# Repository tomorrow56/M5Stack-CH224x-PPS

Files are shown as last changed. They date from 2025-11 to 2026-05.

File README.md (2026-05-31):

# M5Stack-CH224x-PPS

An Arduino library and sample sketch collection for controlling CH224A/CH224Q USB PD controllers via I2C on M5Stack (M5Unified compatible), with USB PD PPS/AVS mode voltage adjustment.

## Features

- **Fixed Voltage Mode**: Select from 5V/9V/12V/15V/20V/28V fixed voltages
- **PPS Mode**: Adjust voltage in 0.1V steps within 5.0V～21.0V range
- **AVS Mode**: Variable voltage setting (16-bit precision)
- **Source Capabilities Analysis**: Detailed display of SRCCAP/EPR_SRCCAP messages
- **PDO Type Identification**: Automatic detection of Fixed/Battery/Variable/PPS Supply
- **CH224A Library**: Reusable library class (`src/CH224A.h`)

## Project Structure

```text
M5Stack-CH224x-PPS/
├── src/
│   ├── CH224A.h          # CH224A library header
│   └── CH224A.cpp        # CH224A library implementation
├── examples/
│   ├── M5Stack_PDtrigger_PPS/             # PD Analyzer with PDO decode
│   └── test/                              # Test and debug sketches
│       ├── M5Stack_CH224A_PPS/            # PPS voltage control (with GUI)
│       ├── CH224A_PDO_Test/               # PDO decode test (serial output)
│       ├── I2C_Scanner/                   # I2C device scanner
│       ├── PPS_Test/                      # PPS voltage sweep test
│       └── Simple_Test/                   # Fixed voltage auto-switch test
├── kicad/                                 # KiCad design files
│   └── M5_PDtrigger_PPS_v2/               # Hardware design v2
├── case/                                  # 3D printable case files
│   └── M5Stack_PDtrigger/                 # M5Stack PD Trigger case
├── README_JP.md           # Japanese documentation
├── README.md             # This file
├── WIRING.md             # Detailed wiring information
└── LICENSE               # MIT license
```

## Hardware Requirements

### Required Components

- **M5Stack** (M5Unified compatible device: Core Basic, Core2, CoreS3, etc.)
- **CH224A/CH224Q** USB PD controller (ESSOP10/DFN10 package)
- **USB Type-C connector**
- **1μF ceramic capacitor** (between VHV-GND)

### Pin Connections

| M5Stack | CH224A | Description |
|---|---|---|
| GPIO21 | Pin 3 (CFG3/SDA)| I2C data line |
| GPIO22 | Pin 2 (CFG2/SCL)| I2C clock line |
| GND | Pin 0 (GND) | Ground |
| GPIO2 (※) | VBUSEN | Output enable |
| GPIO12 (※) | Pin 10 (PG) | Power Good input |

※ Used in sample sketches. Can be changed according to your purpose.

**Important**: When using CFG2/CFG3 pins as I2C, do not connect resistors to these pins (leave them floating).

For detailed wiring information, see [WIRING.md](WIRING.md).

## 3D Printable Case

A custom 3D printable case is available for the M5Stack PD Trigger:

### Files Available

- **`case/M5Stack_PDtrigger/PDtrigger_10mm_224A.stl`** - Main case body (STL format)
- **`case/M5Stack_PDtrigger/PDtrigger_10mm_224A.3mf`** - Main case body (3MF format)
- **`case/M5Stack_PDtrigger/text.stl`** - Text labels/decorations (STL format)

### Printing Recommendations

- **Layer Height**: 0.2mm for quality
- **Infill**: 20-30% 
- **Support**: Required for overhangs
- **Material**: PLA or PETG recommended

The case is designed to accommodate the CH224A/CH224Q PD controller and provide proper mounting for the M5Stack device.

## Software Requirements

### Arduino IDE Setup

1. **Add M5Stack Board Manager**:
   - Arduino IDE → File → Preferences
   - Add to "Additional Board Manager URLs":

     ```text
     https://m5stack.oss-cn-shenzhen.aliyuncs.com/resource/arduino/package_m5stack_index.json
     ```

2. **Install M5Stack Board**:
   - Tools → Board → Boards Manager
   - Search for "M5Stack" and install

3. **Install M5Unified Library**:
   - Sketch → Include Library → Manage Libraries
   - Search for "M5Unified" and install

### Board Settings

- **Board**: M5Stack-Core-ESP32 (or your M5Stack device)
- **Upload Speed**: 921600
- **Flash Frequency**: 80MHz

## Sample Sketches

### M5Stack_PDtrigger_PPS

M5Stack PD Analyzer - Main application for USB PD charger analysis and voltage control.

**Key Features**:

- Fixed voltage mode switching (5V/9V/12V/15V/20V)
- PPS mode voltage adjustment (0.1V steps)
- PDO Decode screen for detailed Source Capabilities display
- Real-time voltage/current measurement and PG (Power Good) display

**Operation**:

- **Button A (Left)**: Decrease voltage / Enter PDO Decode at PDO=0
- **Button B (Center)**: Output ON/OFF toggle
- **Button C (Right)**: Increase voltage / Enter PPS control at PDO=4 / Exit from PDO Decode

### M5Stack_CH224A_PPS

Legacy version of PPS voltage control GUI application.

### test/ Folder

Contains the following test and debug sketches.

#### CH224A_PDO_Test

Debug sketch that outputs PDO data to serial monitor. Displays raw data and parsed results of Source Capabilities.

#### I2C_Scanner

Scans I2C bus and displays device addresses. Used for CH224A connection verification.

#### PPS_Test

Test sketch that automatically sweeps PPS voltage from 5.5V to 20.0V in 0.5V steps.

#### Simple_Test

Basic test sketch that automatically switches fixed voltages (5V→9V→12V→15V→20V→28V) every 2 seconds.

## CH224A Library

Provides a reusable library class in `src/CH224A.h` and `src/CH224A.cpp`.

### Usage Example

```cpp
#include <Wire.h>
#include "src/CH224A.h"

CH224A ch224a;

void setup() {
  Wire.begin(21, 22);
  
  if (ch224a.begin()) {
    // Fixed voltage setting
    ch224a.setVoltage9V();
    
    // PPS voltage setting (9.5V)
    ch224a.setPPSVoltage(9.5);
    
    // AVS voltage setting (12.0V)
    ch224a.setAVSVoltage(12.0);
  }
}
```

### API

| Method | Description |
|---|---|
| `begin(TwoWire &wire)` | Initialize and check connection |
| `isConnected()` | Check I2C connection |
| `setVoltage5V()` ～ `setVoltage28V()` | Fixed voltage setting |
| `setFixedVoltage(CH224A_VoltageMode)` | Voltage mode setting |
| `setPPSVoltage(float voltage)` | PPS voltage setting (in volts) |
| `setPPSVoltageRaw(uint8_t value)` | PPS voltage setting (0.1V units) |
| `setAVSVoltage(float voltage)` | AVS voltage setting (in volts) |
| `setAVSVoltageRaw(uint16_t value)`| AVS voltage setting (0.1V units) |
| `readRegister(reg, &value)` | Register read |
| `writeRegister(reg, value)` | Register write |
| `readSourceCapabilities(data, length)` | Read Source Capabilities |
| `getPDOCount(header)` | Get PDO count |
| `getPDOType(pdo)` | Get PDO type (0:Fixed, 1:Variable, 3:PPS) |
| `parseFixedPDO(pdo, voltage, current)` | Parse Fixed PDO |
| `parseVariablePDO(pdo, minV, maxV, current)` | Parse Variable PDO |
| `parsePPSPDO(pdo, minV, maxV, current)` | Parse PPS PDO |
| `decodeHeader(header)` | Decode and display PDO header |
| `decodePDOs(data, numPDO)` | Decode and display PDO data |

## CH224A Technical Specifications

### Supported Protocols

- USB PD3.2 EPR (Extended Power Range)
- USB PD PPS (Programmable Power Supply)
- USB PD AVS (Adjustable Voltage Supply)
- USB PD SPR (Standard Power Range)
- BC1.2

### Electrical Specifications

- **Input Voltage Range**: 4V～30V
- **I2C Communication Speed**: Max 400kHz
- **I2C Address**: 0x22 (default) or 0x23

### Register Map

| Address | Name | Description |
|---|---|---|
| 0x09 | I2C_STATUS | I2C status |
| 0x0A | VOLTAGE_CTRL | Voltage control (0-7) |
| 0x50 | CURRENT_DATA | Current data (50mA units) |
| 0x51-0x52  | AVS_VOLTAGE | AVS voltage (16-bit) |
| 0x53 | PPS_VOLTAGE | PPS voltage (0.1V units) |
| 0x60-0x7F  | SRCCAP_DATA | Source Capabilities |
| 0x80-0x8F  | EPR_SRCCAP_DATA | EPR Source Capabilities |

### Voltage Control Register (0x0A) Values

| Value | Mode |
|---|---|
| 0 | 5V Fixed |
| 1 | 9V Fixed |
| 2 | 12V Fixed  |
| 3 | 15V Fixed  |
| 4 | 20V Fixed  |
| 5 | 28V Fixed  |
| 6 | PPS Mode |
| 7 | AVS Mode |

## Troubleshooting

### CH224A Not Responding

1. Check SDA/SCL wiring
2. Verify I2C address (use `I2C_Scanner` sketch)
3. Ensure no resistors are connected to CFG2/CFG3 pins
4. Add 4.7kΩ pull-up resistors if necessary

### Voltage Not Changing

1. Verify that the USB PD charger supports PPS/AVS
2. Use a USB PD compatible cable
3. Ensure settings are within the charger's supported voltage range

### Screen Not Displaying

1. Verify M5Unified library is properly installed
2. Check that the correct board is selected

## License

MIT License - see [LICENSE](LICENSE) for details

## References

- [CH224A Datasheet](https://wch.cn)
- [M5Stack Official Documentation](https://docs.m5stack.com)
- [M5Unified GitHub](https://github.com/m5stack/M5Unified)
- [USB Power Delivery Specification](https://www.usb.org/usb-charger-pd)

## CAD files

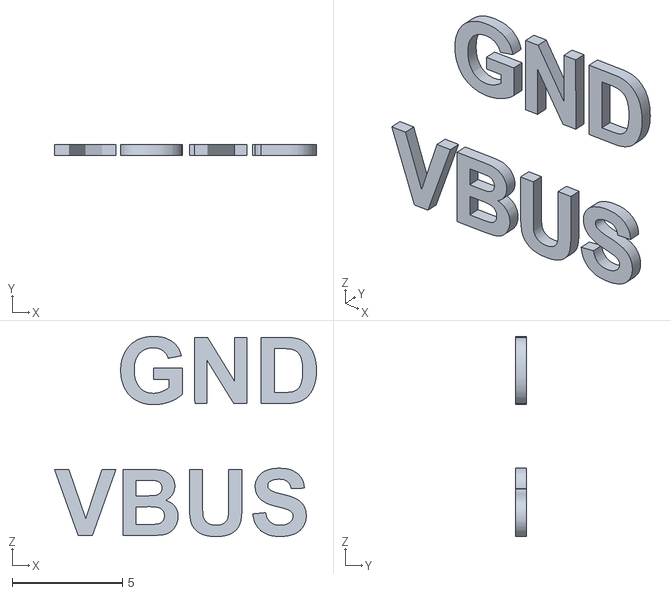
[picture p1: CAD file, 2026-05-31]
case/M5Stack_PDtrigger/text.stl
11.9 x 0.5 x 9.09

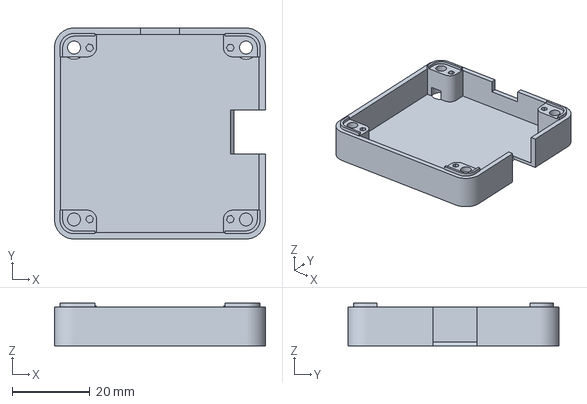
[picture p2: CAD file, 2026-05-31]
case/M5Stack_PDtrigger/PDtrigger_10mm_224A.3mf
54.3 x 54.3 x 11.1 mm
PDtrigger_10mm_224A.stl
text.stl

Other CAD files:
case/M5Stack_PDtrigger/PDtrigger_10mm_224A.stl

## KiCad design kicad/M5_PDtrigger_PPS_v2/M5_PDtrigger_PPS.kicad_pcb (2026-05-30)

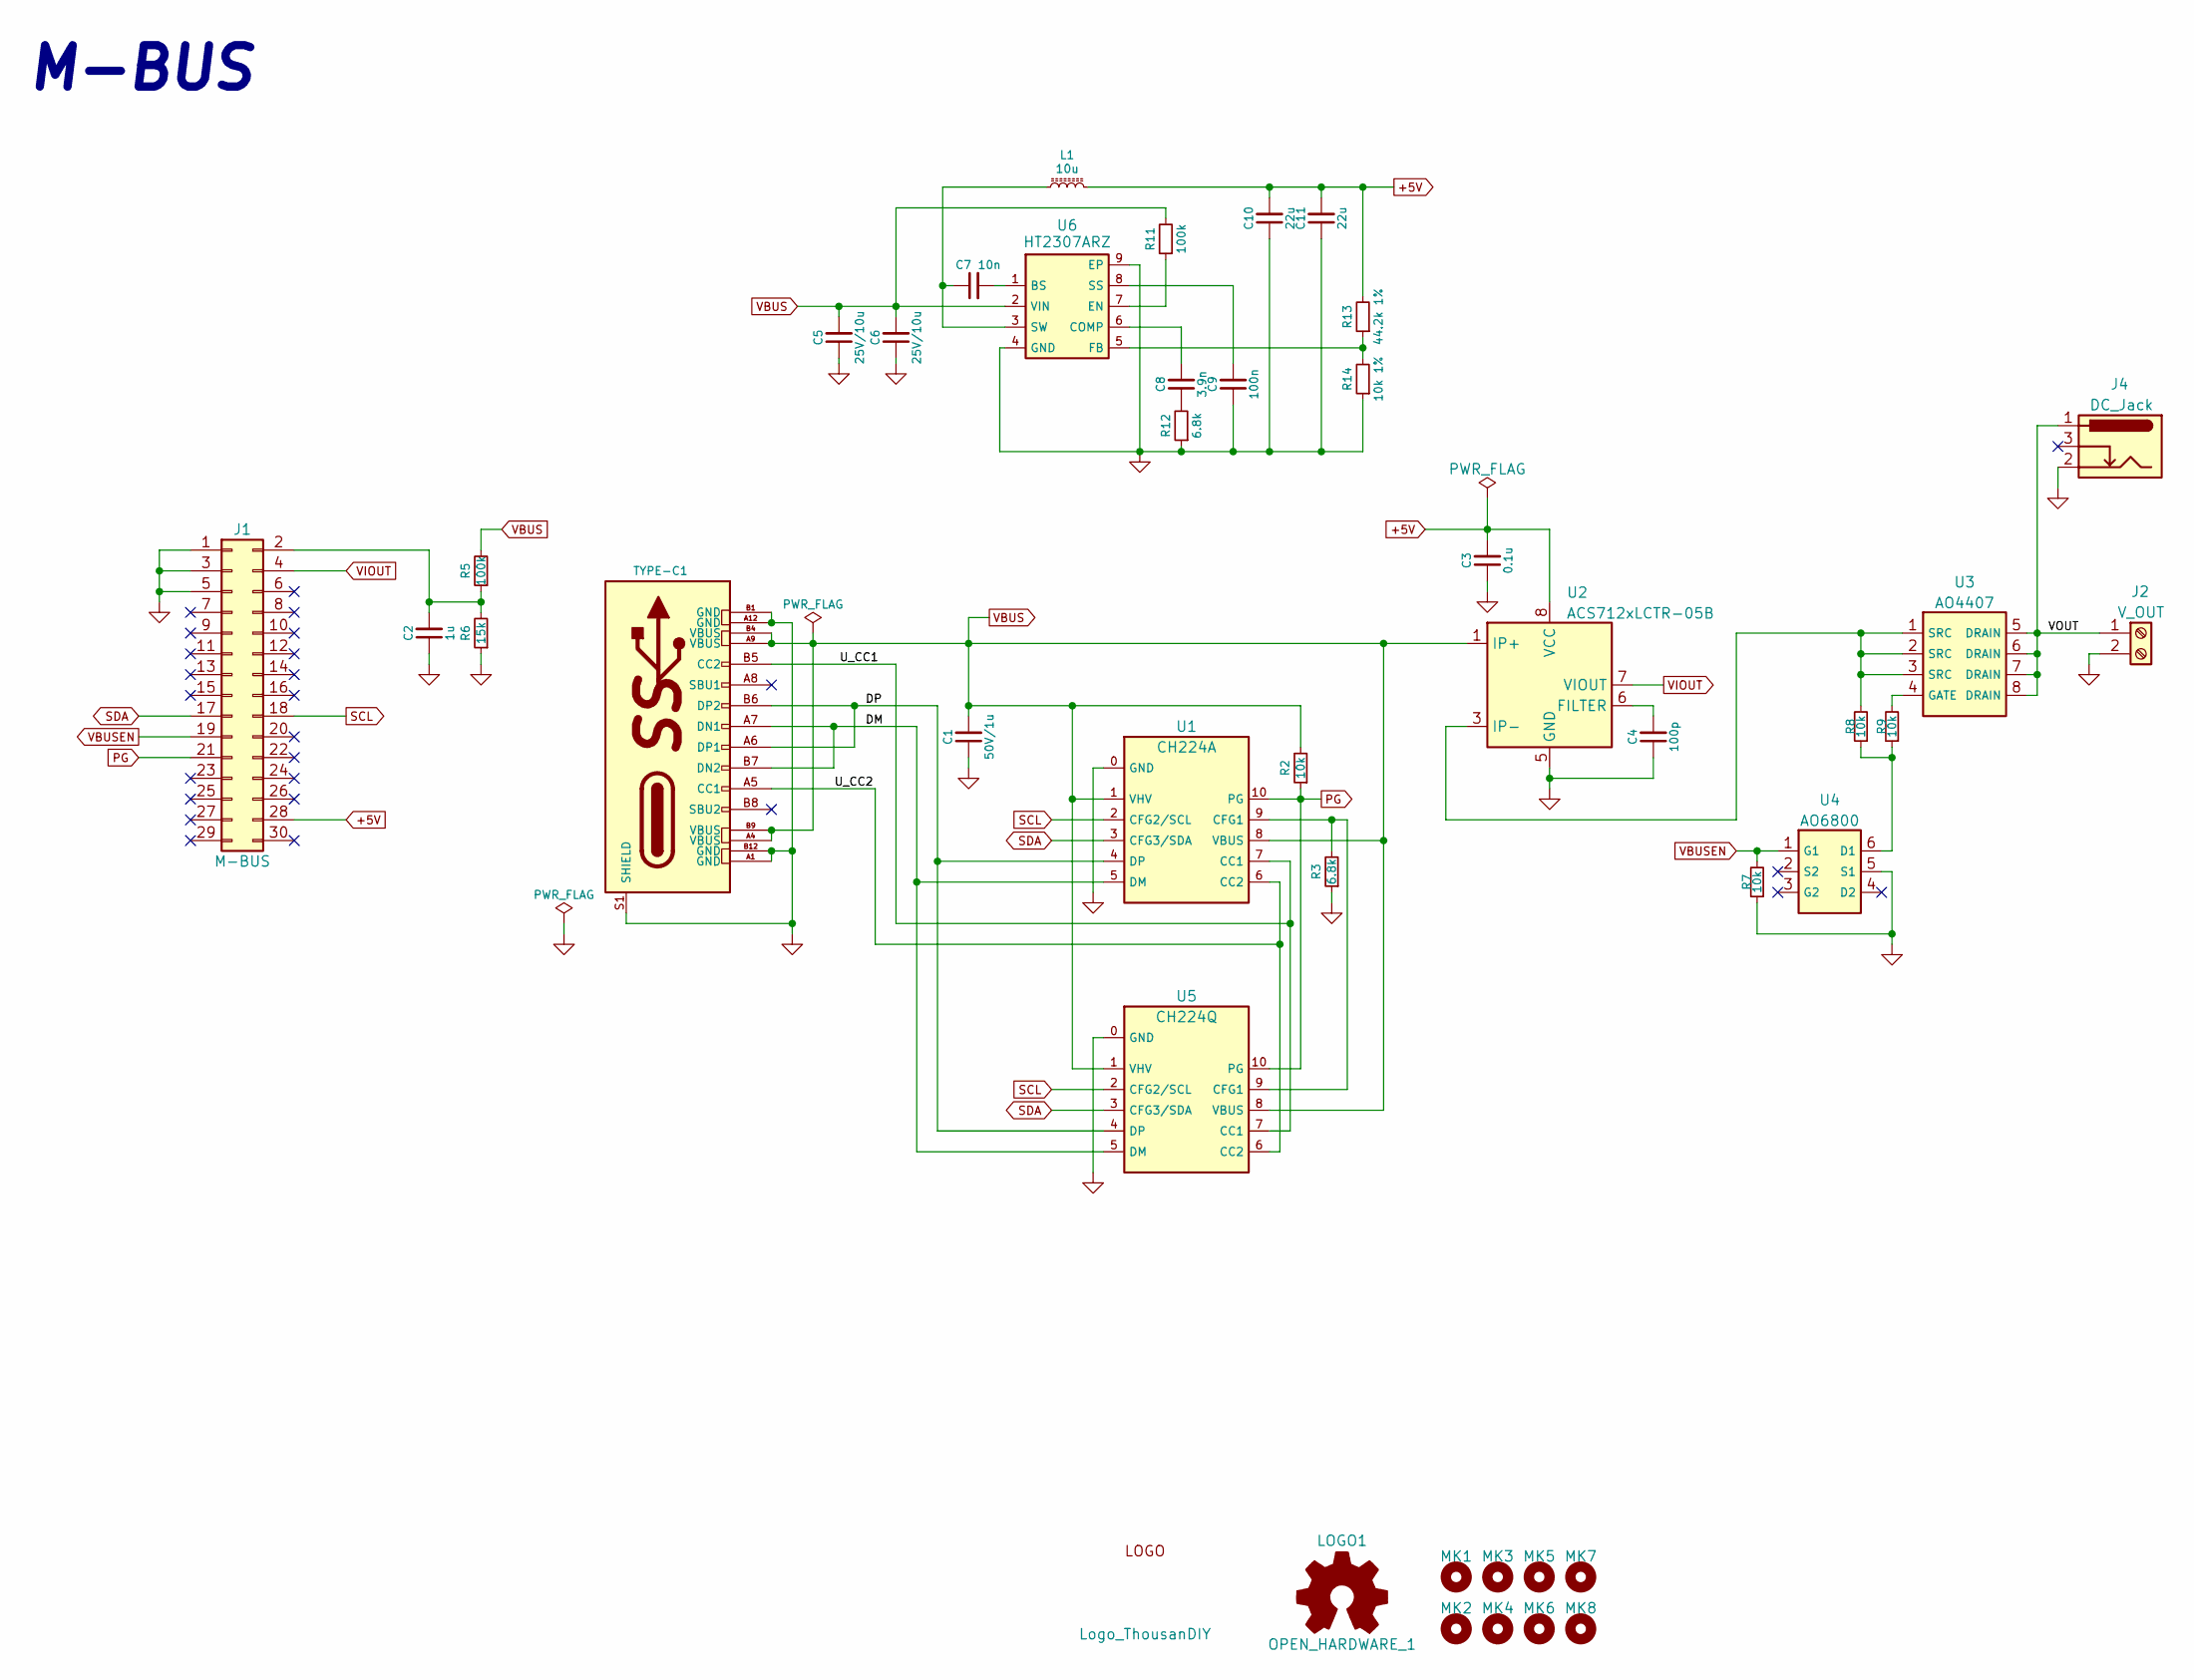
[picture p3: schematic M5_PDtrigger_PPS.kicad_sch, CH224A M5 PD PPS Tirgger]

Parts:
C1: 50V/1u; C_0603_1608Metric
C2: 1u; C_0603_1608Metric
C3: 0.1u; C_0603_1608Metric
C4: 100p; C_0603_1608Metric
C5, C6: 25V/10u; C_0603_1608Metric
C7: 10n; C_0603_1608Metric
C8: 3.9n; C_0603_1608Metric
C9: 100n; C_0603_1608Metric
C10, C11: 22u; C_0603_1608Metric
J1: M-BUS; Pin_Header_MBUS_SMD_TH
J2: V_OUT; TB111-2-2
J4: DC_Jack; BarrelJack_Horizontal
L1: 10u; L_Chilisin_BMRB00050518-B
LOGO1: OPEN_HARDWARE_1; OSHW-logo_silkscreen-front_3mm
MK1, MK2, MK3, MK4: Mounting_Hole; MountingHole_M3_mod
MK5, MK6, MK7, MK8: Mounting_Hole; MountingHole_M2_mod
R2, R7, R8, R9: 10k; R_0603_1608Metric
R3, R12: 6.8k; R_0603_1608Metric
R5, R11: 100k; R_0603_1608Metric
R6: 15k; R_0603_1608Metric
R13: 44.2k 1%; R_0603_1608Metric
R14: 10k 1%; R_0603_1608Metric
TYPE-C1: TYPE-C-31-M-12; USB_C_Receptacle_HRO_TYPE-C-31-M-12
U1: CH224A; ESSOP-10_3.9x4.9mm_P1.00mm_ThermalVia
U2: ACS712xLCTR-05B; SOIC-8_3.9x4.9mm_P1.27mm
U3: AO4407; SOP-8_3.9x4.9mm_P1.27mm
U4: AO6800; SOT-23-6
U5: CH224Q; DFN-10_2x2mm_P0.4mm_ThermalVia
U6: HT2307ARZ; HSOP-8-1EP_3.9x4.9mm_P1.27mm_EP2.41x3.1mm_ThermalVias
logo2: Logo_ThousanDIY; TDIY-LOGO-S

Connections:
+5V: C3.2, C10.2, C11.2, J1.28, L1.2, R13.2, U2.8 (VCC)
/DM: TYPE-C1.A7 (DN1), TYPE-C1.B7 (DN2), U1.5 (DM), U5.5 (DM)
/DP: TYPE-C1.A6 (DP1), TYPE-C1.B6 (DP2), U1.4 (DP), U5.4 (DP)
/U_CC1: TYPE-C1.B5 (CC2), U1.7 (CC1), U5.7 (CC1)
/U_CC2: TYPE-C1.A5 (CC1), U1.6 (CC2), U5.6 (CC2)
/VOUT: J2.1, J4.1, U3.5 (DRAIN), U3.6 (DRAIN), U3.7 (DRAIN), U3.8 (DRAIN)
GND: C1.1, C2.1, C3.1, C4.1, C5.1, C6.1, C9.1, C10.1, C11.1, J1.1, J1.3, J1.5, J2.2, J4.2, R3.1, R6.1, R7.1, R12.1, R14.1, TYPE-C1.A1 (GND), TYPE-C1.A12 (GND), TYPE-C1.B1 (GND), TYPE-C1.B12 (GND), TYPE-C1.S1 (SHIELD), U1.0 (GND), U2.5 (GND), U4.5 (S1), U5.0 (GND), U6.4 (GND), U6.9 (EP)
unnamed: C8.1, R12.2
unnamed: C2.2, J1.2, R5.1, R6.2
unnamed: R8.2, U2.3 (IP-), U2.4 (IP-), U3.1 (SRC), U3.2 (SRC), U3.3 (SRC)
unnamed: R3.2, U1.9 (CFG1), U5.9 (CFG1)
unnamed: C4.2, U2.6 (FILTER)
unnamed: R9.2, U3.4 (GATE)
unnamed: R8.1, R9.1, U4.6 (D1)
unnamed: C7.2, U6.1 (BS)
unnamed: C8.2, U6.6 (COMP)
unnamed: R11.1, U6.7 (EN)
unnamed: R13.1, R14.2, U6.5 (FB)
unnamed: C9.2, U6.8 (SS)
unnamed: C7.1, L1.1, U6.3 (SW)
PG: J1.21, R2.1, U1.10 (PG), U5.10 (PG)
SCL: J1.18, U1.2 (CFG2/SCL), U5.2 (CFG2/SCL)
SDA: J1.17, U1.3 (CFG3/SDA), U5.3 (CFG3/SDA)
VBUS: C1.2, C5.2, C6.2, R2.2, R5.2, R11.2, TYPE-C1.A4 (VBUS), TYPE-C1.A9 (VBUS), TYPE-C1.B4 (VBUS), TYPE-C1.B9 (VBUS), U1.1 (VHV), U1.8 (VBUS), U2.1 (IP+), U2.2 (IP+), U5.1 (VHV), U5.8 (VBUS), U6.2 (VIN)
VBUSEN: J1.19, R7.2, U4.1 (G1)
VIOUT: J1.4, U2.7 (VIOUT)

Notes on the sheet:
M-BUS

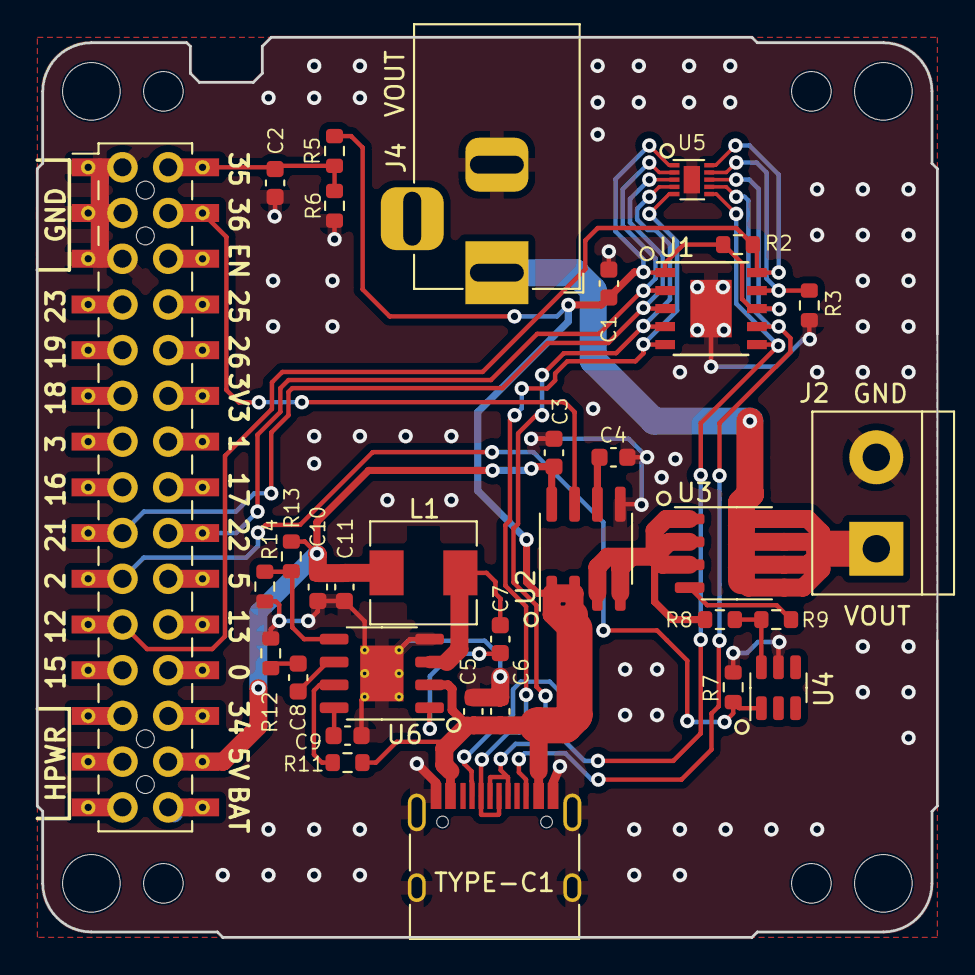
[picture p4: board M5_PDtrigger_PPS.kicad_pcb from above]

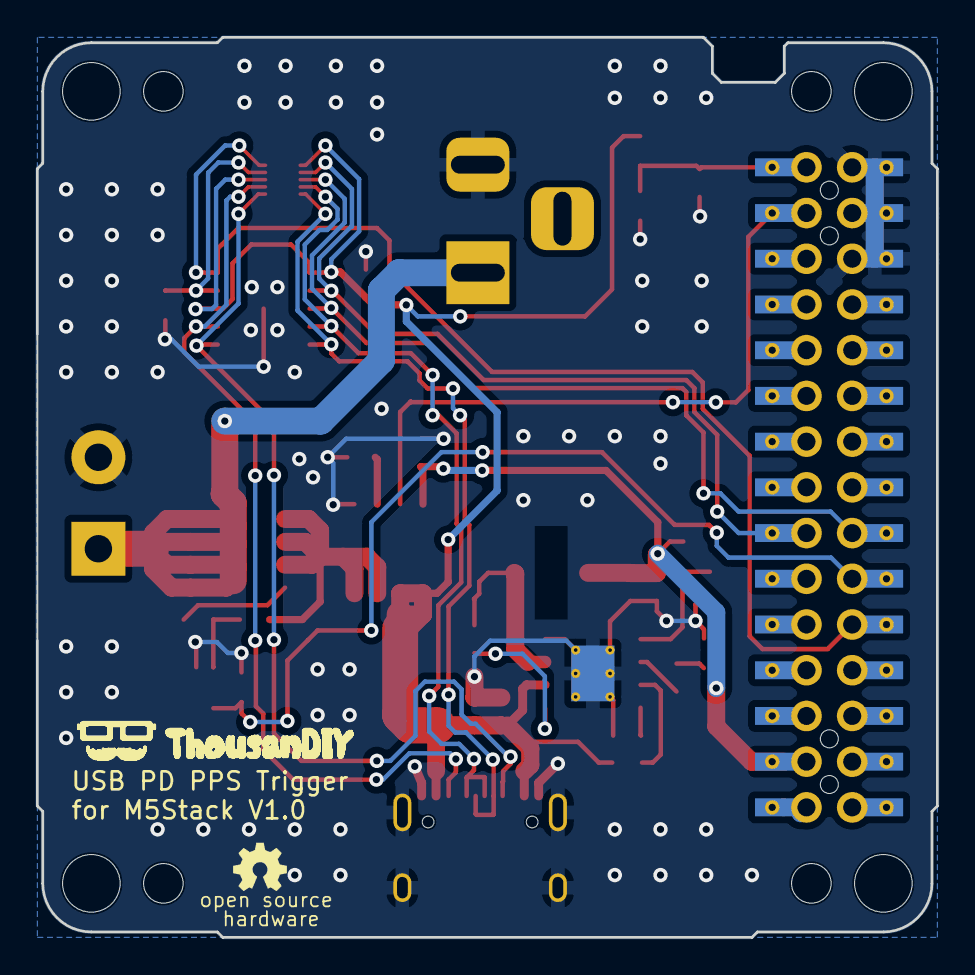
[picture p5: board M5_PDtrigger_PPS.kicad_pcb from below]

Board: 2 copper layers, 50.0 x 50.0 mm, 43 parts (2 on the bottom side), 26 nets.

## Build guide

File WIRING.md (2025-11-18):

# 配線ガイド

このドキュメントでは、M5Stack Core BasicとCH224Aチップの詳細な配線方法を説明します。

## 必要な部品

### 主要部品
- M5Stack Core Basic × 1
- CH224A USB PDチップ(ESSOP10またはDFN10パッケージ) × 1
- USB Type-Cコネクタ × 1
- 1μFセラミックコンデンサ × 1

### オプション部品
- LED × 1(Power Good表示用)
- 抵抗(330Ω～1kΩ) × 1(LED用)
- プルアップ抵抗(4.7kΩ) × 2(I2C用、必要な場合)

## CH224Aピン配置

### ESSOP10/DFN10パッケージ

```
        CH224A
    +------------+
  0 | GND        | 10  PG
  1 | VHV        | 9   CFG1
  2 | CFG2/SCL   | 8   VBUS
  3 | CFG3/SDA   | 7   CC1
  4 | DP         | 6   CC2
  5 | DM         |
    +------------+
```

## 基本配線図

### M5Stack ⇔ CH224A接続

```
M5Stack Core Basic          CH224A
+------------------+        +------------------+
|                  |        |                  |
| GPIO21 (SDA) ----+--------+--- Pin 3 (SDA)  |
| GPIO22 (SCL) ----+--------+--- Pin 2 (SCL)  |
| GND          ----+--------+--- Pin 0 (GND)  |
|                  |        |                  |
+------------------+        +------------------+
```

### CH224A完全配線図

```
USB Type-C Connector                CH224A                    M5Stack
+-------------------+          +----------------+         +-----------+
|                   |          |                |         |           |
| VBUS -------------|----------| Pin 1 (VHV)    |         |           |
|                   |    |     |                |         |           |
|                   |  [1μF]   | Pin 8 (VBUS)---|         |           |
|                   |    |     |                |         |           |
| GND --------------|----+-----| Pin 0 (GND) ---|---------|--- GND    |
|                   |          |                |         |           |
| D+ ---------------|----------| Pin 4 (DP)     |         |           |
| D- ---------------|----------| Pin 5 (DM)     |         |           |
|                   |          |                |         |           |
| CC1 --------------|----------| Pin 7 (CC1)    |         |           |
| CC2 --------------|----------| Pin 6 (CC2)    |         |           |
|                   |          |                |         |           |
+-------------------+          | Pin 2 (SCL) ---|---------|--- GPIO22 |
                               | Pin 3 (SDA) ---|---------|--- GPIO21 |
                               |                |         |           |
                               | Pin 9 (CFG1)   |         |           |
                               | (フローティング)|         |           |
                               |                |         |           |
                               | Pin 10 (PG) ---+--- [LED+抵抗] --- GND
                               |                |         |           |
                               +----------------+         +-----------+
```

## 詳細配線手順

### 1. 電源配線

CH224AのVHVピン(Pin 1)にUSB Type-CのVBUSを接続します。VHVとGND間に1μFのセラミックコンデンサを配置してください。

```
VBUS ---+--- VHV (Pin 1)
        |
      [1μF]
        |
       GND (Pin 0)
```

### 2. USB Data配線

USB Type-CのD+/D-をCH224AのDP/DMピンに接続します。

```
USB D+ --- DP (Pin 4)
USB D- --- DM (Pin 5)
```

### 3. Type-C CC配線

Type-CのCC1/CC2ピンをCH224Aに接続します。これらのピンはUSB PDの通信に使用されます。

```
Type-C CC1 --- CC1 (Pin 7)
Type-C CC2 --- CC2 (Pin 6)
```

### 4. 電圧検出配線

VBUSをCH224AのVBUSピン(Pin 8)にも接続します。これは電圧検出用です。

```
VBUS --- VBUS (Pin 8)
```

### 5. I2C配線(M5Stack接続)

M5StackのI2CピンをCH224Aに接続します。

```
M5Stack GPIO21 (SDA) --- CFG3/SDA (Pin 3)
M5Stack GPIO22 (SCL) --- CFG2/SCL (Pin 2)
M5Stack GND          --- GND (Pin 0)
```

**重要**: CFG2とCFG3ピンをI2Cとして使用する場合、これらのピンに抵抗を接続しないでください。フローティング状態にします。

### 6. CFG1ピン設定

CFG1ピン(Pin 9)はフローティング(未接続)のままにします。I2C制御を使用する場合、このピンは使用しません。

### 7. Power Goodピン(オプション)

PGピン(Pin 10)は、電源が正常に供給されているときにLOWになります。LEDで状態を表示する場合:

```
PG (Pin 10) --- [330Ω抵抗] --- LED(アノード)
                               LED(カソード) --- GND
```

### 8. I2Cプルアップ抵抗(必要な場合)

M5StackのI2Cピンには内部プルアップがありますが、配線が長い場合や動作が不安定な場合は、外部プルアップ抵抗(4.7kΩ)を追加してください。

```
3.3V --- [4.7kΩ] --- SDA (GPIO21)
3.3V --- [4.7kΩ] --- SCL (GPIO22)
```

## 配線チェックリスト

配線完了後、以下の項目を確認してください:

- [ ] VHVとGND間に1μFコンデンサが接続されている
- [ ] USB D+がDPピンに接続されている
- [ ] USB D-がDMピンに接続されている
- [ ] Type-C CC1がCC1ピンに接続されている
- [ ] Type-C CC2がCC2ピンに接続されている
- [ ] VBUSがVBUSピン(Pin 8)に接続されている
- [ ] M5Stack GPIO21がCFG3/SDA(Pin 3)に接続されている
- [ ] M5Stack GPIO22がCFG2/SCL(Pin 2)に接続されている
- [ ] M5StackとCH224AのGNDが共通接続されている
- [ ] CFG1ピン(Pin 9)がフローティング状態である
- [ ] CFG2/CFG3ピンに抵抗が接続されていない

## I2Cアドレスの確認

CH224AのI2Cアドレスは通常0x22ですが、0x23の場合もあります。スケッチ内で正しいアドレスを設定してください。

I2Cスキャナーを使用してアドレスを確認する場合:

```cpp
#include <Wire.h>

void setup() {
  Serial.begin(115200);
  Wire.begin(21, 22);
  
  Serial.println("I2C Scanner");
  for (byte address = 1; address < 127; address++) {
    Wire.beginTransmission(address);
    byte error = Wire.endTransmission();
    
    if (error == 0) {
      Serial.print("I2C device found at address 0x");
      if (address < 16) Serial.print("0");
      Serial.println(address, HEX);
    }
  }
}

void loop() {}
```

## トラブルシューティング

### I2C通信エラー

**症状**: CH224Aが応答しない

**確認事項**:
1. SDA/SCLの配線が正しいか
2. GNDが共通接続されているか
3. CFG2/CFG3ピンに抵抗が接続されていないか
4. I2Cアドレスが正しいか(0x22または0x23)

**対策**:
- プルアップ抵抗(4.7kΩ)をSDA/SCLに追加
- 配線を短くする
- I2Cスキャナーでアドレスを確認

### 電圧が変わらない

**症状**: 電圧設定を変更しても出力電圧が変わらない

**確認事項**:
1. USB PD充電器がPPSをサポートしているか
2. USB Type-Cケーブルがフル機能対応か
3. CC1/CC2ピンが正しく接続されているか
4. VBUSピン(Pin 8)が接続されているか

**対策**:
- PPS対応のUSB PD充電器を使用
- USB PD対応のケーブルを使用
- CC1/CC2の配線を確認

### Power Goodが動作しない

**症状**: PGピンの出力が変化しない

**確認事項**:
1. VHVに電源が供給されているか
2. USB PD通信が正常に行われているか

**対策**:
- VHVとGND間の電圧を測定(5V以上あるか確認)
- USB PD充電器を交換してみる

## 安全上の注意

1. **短絡防止**: 配線時は必ず電源を切ってください
2. **極性確認**: コンデンサやLEDの極性を確認してください
3. **電圧範囲**: CH224Aの最大入力電圧(30V)を超えないでください
4. **発熱**: 高電圧・高電流使用時は発熱に注意してください

## 参考資料

- CH224Aデータシート: https://wch.cn
- USB Type-C仕様: https://www.usb.org
- M5Stack公式ドキュメント: https://docs.m5stack.com

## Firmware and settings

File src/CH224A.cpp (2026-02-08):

/*
 * CH224A.cpp - CH224A USB PD Controller Library Implementation
 */

#include "CH224A.h"

// コンストラクタ
CH224A::CH224A(uint8_t i2cAddress) {
  _i2cAddress = i2cAddress;
  _i2cPort = nullptr;
}

// 初期化
bool CH224A::begin(TwoWire &wirePort) {
  _i2cPort = &wirePort;
  
  // I2C通信確認
  return isConnected();
}

// I2C通信確認
bool CH224A::isConnected() {
  if (_i2cPort == nullptr) {
    return false;
  }
  
  _i2cPort->beginTransmission(_i2cAddress);
  return (_i2cPort->endTransmission() == 0);
}

// レジスタ書き込み(8ビット)
bool CH224A::writeRegister(uint8_t reg, uint8_t value) {
  if (_i2cPort == nullptr) {
    return false;
  }
  
  _i2cPort->beginTransmission(_i2cAddress);
  _i2cPort->write(reg);
  _i2cPort->write(value);
  uint8_t error = _i2cPort->endTransmission();
  
  delay(50);  // 設定反映待ち
  
  return (error == 0);
}

// レジスタ書き込み(16ビット)
bool CH224A::writeRegister16(uint8_t reg, uint16_t value) {
  if (_i2cPort == nullptr) {
    return false;
  }
  
  // 低位バイトを先に書き込み
  uint8_t lowByte = value & 0xFF;
  uint8_t highByte = (value >> 8) & 0xFF;
  
  bool success = true;
  success &= writeRegister(reg, lowByte);
  success &= writeRegister(reg + 1, highByte);
  
  return success;
}

// レジスタ読み込み(8ビット)
bool CH224A::readRegister(uint8_t reg, uint8_t &value) {
  if (_i2cPort == nullptr) {
    return false;
  }
  
  _i2cPort->beginTransmission(_i2cAddress);
  _i2cPort->write(reg);
  uint8_t error = _i2cPort->endTransmission(false);
  
  if (error != 0) {
    return false;
  }
  
  uint8_t bytesReceived = _i2cPort->requestFrom(_i2cAddress, (uint8_t)1);
  
  if (bytesReceived == 1) {
    value = _i2cPort->read();
    return true;
  }
  
  return false;
}

// レジスタ読み込み(16ビット)
bool CH224A::readRegister16(uint8_t reg, uint16_t &value) {
  if (_i2cPort == nullptr) {
    return false;
  }
  
  uint8_t lowByte, highByte;
  bool success = true;
  
  success &= readRegister(reg, lowByte);
  success &= readRegister(reg + 1, highByte);
  
  if (success) {
    value = ((uint16_t)highByte << 8) | lowByte;
  }
  
  return success;
}

// 固定電圧設定
bool CH224A::setFixedVoltage(CH224A_VoltageMode mode) {
  return writeRegister(CH224A_REG_VOLTAGE_CTRL, (uint8_t)mode);
}

// 5V設定
bool CH224A::setVoltage5V() {
  return setFixedVoltage(CH224A_VOLTAGE_5V);
}

// 9V設定
bool CH224A::setVoltage9V() {
  return setFixedVoltage(CH224A_VOLTAGE_9V);
}

// 12V設定
bool CH224A::setVoltage12V() {
  return setFixedVoltage(CH224A_VOLTAGE_12V);
}

// 15V設定
bool CH224A::setVoltage15V() {
  return setFixedVoltage(CH224A_VOLTAGE_15V);
}

// 20V設定
bool CH224A::setVoltage20V() {
  return setFixedVoltage(CH224A_VOLTAGE_20V);
}

// 28V設定(EPR対応充電器のみ)
bool CH224A::setVoltage28V() {
  return setFixedVoltage(CH224A_VOLTAGE_28V);
}

// PPS電圧設定(電圧値で指定)
bool CH224A::setPPSVoltage(float voltage) {
  // 電圧を0.1V単位に変換(例: 9.0V → 90)
  uint8_t voltageRaw = (uint8_t)(voltage * 10.0 + 0.5);
  return setPPSVoltageRaw(voltageRaw);
}

// PPS電圧設定(生値で指定)
bool CH224A::setPPSVoltageRaw(uint8_t voltage) {
  bool success = true;
  
  // PPS電圧値を設定
  success &= writeRegister(CH224A_REG_PPS_VOLTAGE, voltage);
  
  // PPSモードに切り替え
  success &= setFixedVoltage(CH224A_VOLTAGE_PPS);
  
  return success;
}

// AVS電圧設定(電圧値で指定)
bool CH224A::setAVSVoltage(float voltage) {
  // 電圧を0.1V単位に変換(例: 9.0V → 90)
  uint16_t voltageRaw = (uint16_t)(voltage * 10.0 + 0.5);
  return setAVSVoltageRaw(voltageRaw);
}

// AVS電圧設定(生値で指定)
bool CH224A::setAVSVoltageRaw(uint16_t voltage) {
  bool success = true;
  
  // AVS電圧値を設定(16ビット)
  success &= writeRegister16(CH224A_REG_AVS_VOLTAGE_L, voltage);
  
  // AVSモードに切り替え
  success &= setFixedVoltage(CH224A_VOLTAGE_AVS);
  
  return success;
}

// PDO解析機能
bool CH224A::readSourceCapabilities(uint8_t* data, size_t length) {
  if (length < (CH224A_REG_PD_DATA_END - CH224A_REG_PD_DATA_START + 1)) {
    return false;
  }
  
  bool success = true;
  for (size_t i = 0; i < length; i++) {
    uint8_t value;
    success &= readRegister(CH224A_REG_PD_DATA_START + i, value);
    if (success) {
      data[i] = value;
    }
  }
  
  return success;
}

uint8_t CH224A::getPDOCount(uint16_t header) {
  return (header >> 12) & 0x7;
}

void CH224A::decodeHeader(uint16_t header) {
  Serial.println("--- Message Header ---");
  Serial.printf("[15]:Extended: %d\n", (header >> 15) & 0x1);
  Serial.printf("[14:12]:Number of Data Objects: %d\n", getPDOCount(header));
  Serial.printf("[11:9]:MessageID: %d\n", (header >> 9) & 0x7);
  Serial.printf("[8]:Port Power Role: %d\n", (header >> 8) & 0x1);
  Serial.printf("[7:6]:Specification Revision: %d\n", (header >> 6) & 0x3);
  Serial.printf("[5]:Port Data Role: %d\n", (header >> 5) & 0x1);
  Serial.printf("[4:0]:Message Type: %d\n", (header >> 0) & 0x1F);
  Serial.println();
}

void CH224A::decodePDOs(uint8_t* data, uint8_t numPDO) {
  Serial.println("=== CH224A Source Capabilities ===");

  for (int i = 0; i < numPDO; i++) {
    uint32_t pdo = data[i*4 + 2] | (data[i*4 + 3] << 8) | (data[i*4 + 4] << 16) | (data[i*4 + 5] << 24);
    // PDO番号を表示
    Serial.printf(" PDO%d:", i + 1);
    // PDOタイプに応じて解析
    uint8_t pdoType = getPDOType(pdo);
    switch (pdoType) {
      case 0: // Fixed Supply
        {
          float voltage, current;
          parseFixedPDO(pdo, voltage, current);
          Serial.printf(" Fixed %5.2fV / %.2fA  (%dW)\n", voltage, current, (int)(voltage * current + 0.5));
        }
        break;
      case 1: // Variable Supply
        {
          float minVoltage, maxVoltage, current;
          parseVariablePDO(pdo, minVoltage, maxVoltage, current);
          Serial.printf(" Variable %.2fV - %.2fV / Imax: %.2fA\n", minVoltage, maxVoltage, current);
        }
        break;
      case 2: // Battery Supply
        {
          float voltage, current;
          parseFixedPDO(pdo, voltage, current);
          Serial.printf(" Battery %5.2fV / %.2fA  (%dW)\n", voltage, current, (int)(voltage * current + 0.5));
        }
        break;
      case 3: // Programmable Supply
        {
          float minVoltage, maxVoltage, current;
          parsePPSPDO(pdo, minVoltage, maxVoltage, current);
          Serial.printf(" PPS %.2fV - %.2fV / Max Current: %.2fA, Max Power: %.2fW\n", 
                      minVoltage, maxVoltage, current, maxVoltage * current);
        }
        break;
    }
  }
}

void CH224A::parseFixedPDO(uint32_t pdo, float& voltage, float& current) {
  // 電圧 (50mV単位)
  uint16_t voltage_50mA = (pdo >> 10) & 0x3FF;
  voltage = voltage_50mA * 0.05f;
  
  // 電流 (10mA単位)
  uint16_t current_10mA = (pdo >> 0) & 0x3FF;
  current = current_10mA * 0.01f;
}

void CH224A::parseVariablePDO(uint32_t pdo, float& minVoltage, float& maxVoltage, float& current) {
  // 最小電圧 (100mV単位)
  uint16_t minVoltageRaw = (pdo >> 8) & 0xFF;
  minVoltage = minVoltageRaw * 0.1f;
  
  // 最大電圧 (100mV単位)
  uint16_t maxVoltageRaw = (pdo >> 17) & 0xFF;
  maxVoltage = maxVoltageRaw * 0.1f;
  
  // 最大電流 (50mA単位)
  uint16_t maxCurrent = (pdo >> 0) & 0x7F;
  current = maxCurrent * 0.05f;
}
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

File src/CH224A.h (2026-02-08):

/*
 * CH224A.h - CH224A USB PD Controller Library
 * 
 * CH224AチップをI2C経由で制御するためのライブラリ
 */

#ifndef CH224A_H
#define CH224A_H

#include <Arduino.h>
#include <Wire.h>

// CH224A I2Cアドレス
#define CH224A_I2C_ADDR_DEFAULT 0x22
#define CH224A_I2C_ADDR_ALT     0x23

// CH224Aレジスタアドレス
#define CH224A_REG_I2C_STATUS     0x09  // I2C状態寄存器
#define CH224A_REG_VOLTAGE_CTRL   0x0A  // 電圧制御寄存器
#define CH224A_REG_CURRENT_DATA   0x50  // 電流データ寄存器
#define CH224A_REG_AVS_VOLTAGE_L  0x51  // AVS電圧配置寄存器(低位)
#define CH224A_REG_AVS_VOLTAGE_H  0x52  // AVS電圧配置寄存器(高位)
#define CH224A_REG_PPS_VOLTAGE    0x53  // PPS電圧配置寄存器
#define CH224A_REG_PD_DATA_START  0x60  // PD電源データ寄存器開始アドレス
#define CH224A_REG_PD_DATA_END    0x8F  // PD電源データ寄存器終了アドレス

// 電圧モード定義
enum CH224A_VoltageMode {
  CH224A_VOLTAGE_5V   = 0,  // 5V固定
  CH224A_VOLTAGE_9V   = 1,  // 9V固定
  CH224A_VOLTAGE_12V  = 2,  // 12V固定
  CH224A_VOLTAGE_15V  = 3,  // 15V固定
  CH224A_VOLTAGE_20V  = 4,  // 20V固定
  CH224A_VOLTAGE_28V  = 5,  // 28V固定(EPR対応充電器のみ)
  CH224A_VOLTAGE_PPS  = 6,  // PPSモード
  CH224A_VOLTAGE_AVS  = 7   // AVSモード
};

class CH224A {
public:
  // コンストラクタ
  CH224A(uint8_t i2cAddress = CH224A_I2C_ADDR_DEFAULT);
  
  // 初期化
  bool begin(TwoWire &wirePort = Wire);
  
  // 固定電圧設定
  bool setFixedVoltage(CH224A_VoltageMode mode);
  bool setVoltage5V();
  bool setVoltage9V();
  bool setVoltage12V();
  bool setVoltage15V();
  bool setVoltage20V();
  bool setVoltage28V();
  
  // PPS電圧設定
  bool setPPSVoltage(float voltage);        // 電圧(V)で設定
  bool setPPSVoltageRaw(uint8_t voltage);   // 0.1V単位の生値で設定
  
  // AVS電圧設定
  bool setAVSVoltage(float voltage);        // 電圧(V)で設定
  bool setAVSVoltageRaw(uint16_t voltage);  // 0.1V単位の生値で設定
  
  // レジスタ読み書き
  bool writeRegister(uint8_t reg, uint8_t value);
  bool writeRegister16(uint8_t reg, uint16_t value);
  bool readRegister(uint8_t reg, uint8_t &value);
  bool readRegister16(uint8_t reg, uint16_t &value);
  
  // I2C通信確認
  bool isConnected();
  
  // I2Cアドレス取得
  uint8_t getI2CAddress() { return _i2cAddress; }
  
  // PDO解析機能
  bool readSourceCapabilities(uint8_t* data, size_t length);
  uint8_t getPDOCount(uint16_t header);
  void decodeHeader(uint16_t header);
  void decodePDOs(uint8_t* data, uint8_t numPDO);
  void parseFixedPDO(uint32_t pdo, float& voltage, float& current);
  void parseVariablePDO(uint32_t pdo, float& minVoltage, float& maxVoltage, float& current);
  void parsePPSPDO(uint32_t pdo, float& minVoltage, float& maxVoltage, float& current);
  uint8_t getPDOType(uint32_t pdo);

private:
  uint8_t _i2cAddress;
  TwoWire *_i2cPort;
};

#endif // CH224A_H

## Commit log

2025-11-18 Initial commit: M5Stack CH224A PPS controller
    - Add main sketch with direct I2C control
    - Add library-based sketch for better maintainability
    - Add CH224A library with PPS/AVS/fixed voltage support
    - Add comprehensive documentation (README, WIRING, PROJECT_OVERVIEW)
    - Add example sketches for testing and I2C scanning
    - Add proper .gitignore for macOS/Arduino/IDE files
    [CH224A.cpp, CH224A.h, I2C_Scanner.ino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]
2025-11-25 Update documentation to reflect current repository structure
    - Add Source Capabilities analysis features to README.md
    - Update PROJECT_OVERVIEW.md with new examples and library structure
    - Document CH224A library usage and API
    - Update version history to v1.1.0
    - Fix file paths and project organization
2025-11-25 Update examples to M5Unified and clean up metadata files
    - Convert all examples from M5Stack.h to M5Unified.h
    - Replace M5.Lcd with M5.Display for M5Unified compatibility
    - Add comprehensive macOS metadata files to .gitignore
    - Remove all ._ files from repository
    - Update pin configurations and I2C handling
    - Improve PPS voltage range and step precision
    - Enhance Source Capabilities display format
    [M5Stack_CH224A_PPS.ino, PPS_Test.ino]
2025-12-07 Fix PDO byte order and add serial debug output for Source Capabilities
    - Correct PDO data byte order from big-endian to little-endian format
    - Add Serial.begin(115200) initialization in setup()
    - Add formatted serial output for received PD data (4 bytes per line)
    - Fix bit shift positions in PDO parsing to match USB-PD specification
    [CH224A_PDO_Test.ino]
2025-12-07 Remove PROJECT_OVERVIEW.md and consolidate documentation into README.md
    - Delete PROJECT_OVERVIEW.md (271 lines of duplicate documentation)
    - Rewrite README.md with improved structure and M5Unified focus
    - Add project structure tree showing src/ and examples/ directories
    - Document all example sketches with usage instructions
    - Add CH224A library usage examples and API reference
    - Update hardware requirements to include CH224K support
    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
2025-12-07 Add Message Header display mode and improve EPR_SRCCAP PDO parsing
    - Add DISPLAY_HEADER mode to show USB-PD message header details
    - Change button operations: A=update, B=cycle modes (SRCCAP/EPR/HEADER), C=show header
    - Implement decodeHeader() to parse message header and extract PDO count
    - Add checkEPRCapable() to detect EPR Mode Capable flag from PDO1 bit[23]
    - Fix EPR PDO offset calculation based on actual SRCCAP PDO count
    - Improve EPR PDO detection with proper little-endian byte order
    - Ad
2026-02-08 v1.0.0: Add PDO parsing functionality and M5Stack PD Analyzer
    - Add PDO parsing functions to CH224A library (readSourceCapabilities, getPDOCount, parseFixedPDO, parseVariablePDO, parsePPSPDO, getPDOType, decodeHeader, decodePDOs)
    - Add M5Stack_PDtrigger_PPS example with PDO decode screen
    - Move test sketches to examples/test/ folder
    - Add keywords.txt and library.properties
    - Add README.md (English) and README_JP.md (Japanese)
    - Force PDO=0 (5V) on startup
    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
2026-02-15 Enhance M5Stack PD Analyzer UI and interaction
    - Add horizontal PDO list with cyan highlight for selected mode
    - Implement framed sub-window style for PDO Decode screen
    - Fix flickering by conditional redraw on mode entry only
    - Display unsupported PDOs in gray text in normal mode list
    - Add long-press auto increment/decrement for PPS voltage (100mV steps)
    - Prevent PPS mode entry if charger does not support PPS
    - Fix PDO list selection sync when exiting PPS mode
    - Adjust UI colors, spacing, and layouts for better usability
    [M5Stack_PDtrigger_PPS.ino]
2026-05-30 Update project structure and documentation
    - Move M5Stack_CH224A_PPS to examples/test/ folder
    - Remove Mac-generated ._ files
    - Update README.md and README_JP.md to reflect current folder structure
    - Fix markdown lint errors (code block language, spacing)
    [M5Stack_CH224A_PPS.ino]
2026-05-30 Complete CH224K to CH224Q update across all files
    - Update library.properties: CH224A/CH224K → CH224A/CH224Q
    - Update keywords.txt: CH224K → CH224Q
    - Update M5Stack_PDtrigger_PPS.ino comment header
    - Fix README.md table alignment and markdown formatting
    - Maintain consistency with KiCad hardware design (CH224Q)
    [M5Stack_PDtrigger_PPS.ino]
2026-05-31 Add 3D printable case files and documentation
    - Add case/ folder with M5Stack PD Trigger 3D print files
    - Include STL and 3MF format files for main case body and text labels
    - Update README.md and README_JP.md with 3D printing section
    - Add printing recommendations and file descriptions
    - Update project structure documentation
    [PDtrigger_10mm_224A.3mf, PDtrigger_10mm_224A.stl, text.stl]
